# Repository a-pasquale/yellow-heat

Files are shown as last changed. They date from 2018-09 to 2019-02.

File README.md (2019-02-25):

# Yellow Heat vegetable oil burner monitoring system

More information about vegetable oil burner technology and installation for Yellow Heat burners is available at https://www.yellowheat.com/

## How it works
This monitoring system is designed to display current fuel level, record and display historical consumption of vegetable oil fuel, and display burner status. 

When the burner turns on or off, the device records the current fuel level. The monitoring device sends this data to the database. Cloud functions calculate fuel consumption when new data is posted in the database. The cross-platform app allows users to configure the monitoring device over bluetooth and displays current fuel level, total consumption, and historical usage. The cloud functions also provide notifications to the user and optionally to the fuel vendor when fuel level drops below a specificied point.

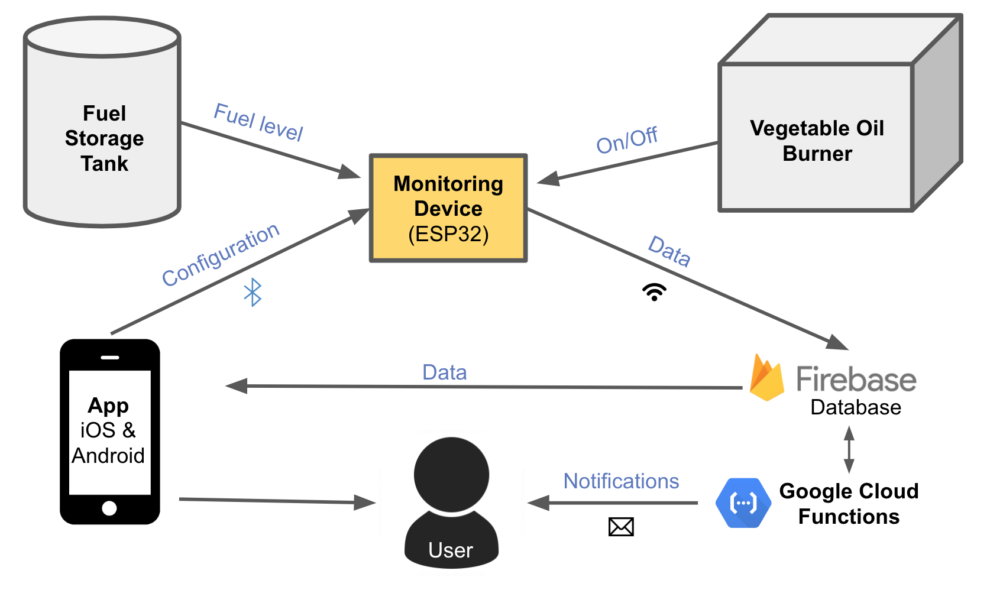
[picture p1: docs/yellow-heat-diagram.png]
Diagram


## Hardware

The Yellow Heat monitoring device is built on an [ESP32 microcontroller](http://esp32.net/). The ESP32 is a low-cost, low-power system on a chip (SoC) series with Wi-Fi & dual-mode Bluetooth capabilities. 

The device is powered with 110VAC converted to 12DC with a RECOM power supply (RAC02-12SGB). This is stepped down to 5V with  an LM2596 DC to DC Buck Converter to power the ESP32 board. The 12V also powers the fuel level sensor.

Fuel level is measured with a [Rochester 6860 magnetic liquid-level gauge](http://www.rochestergauges.com/products/8600.html). With an operating current of 7-8mA at VCC 12V, the guage returns an output of 0.5V - 4.5V. This is converted to a maximum of 3.3V using a voltage divider and indicates fuel level on pin 33.

Burner status (on/off) is measured using another LM2596 DC to DC Buck Converter which converts the 24V signal to 3.3V (HIGH) on pin 18.

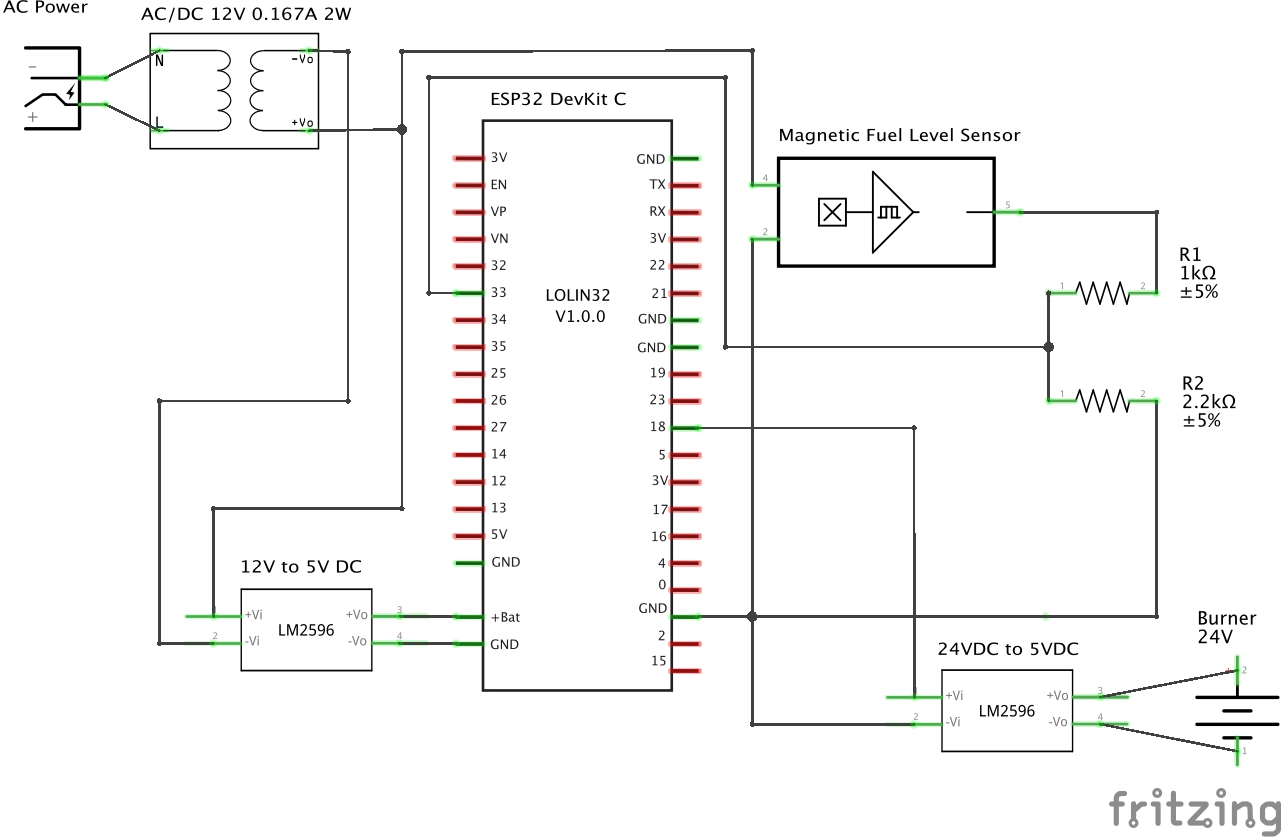
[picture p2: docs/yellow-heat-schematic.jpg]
Schematic


## Firmware
The firmware is developed with [Mongoose OS](https://github.com/cesanta/mongoose-os), an IoT Firmware Development Framework with Over-The-Air firmware updates and remote management, built in flash encryption, a device management dashboard service, and the ability to code in C or JavaScript.

Download this repository:
```bash
$ git clone https://github.com/a-pasquale/yellow-heat.git; cd yellow-heat
```
Build the firmware and flash the device:
```bash
$ mos build --platform esp32
$ mos flash
```
The Mongoose OS dashboard for debugging is very helpful:
```bash
$ mos ui
```

## Ionic App
A cross-platform Ionic App allows users to monitor burner stats, fuel level, and view history. The Ionic framework enables developers to build cross-platform apps in one codebase with the web technologies including Typescript, HTML, and SCSS.

More information about the app is available at [https://github.com/a-pasquale/yellow-heat-app](https://github.com/a-pasquale/yellow-heat-app).

## Google Cloud Functions
These functions calculate total fuel use for the burner and store the current burner status and fuel level. The functions also provide notifications to the user when fuel level drops too low and optionally to the vendor to deliver more fuel.

More information about the cloud functions is available at [https://github.com/a-pasquale/yellow-heat-firebase-functions](https://github.com/a-pasquale/yellow-heat-firebase-functions).

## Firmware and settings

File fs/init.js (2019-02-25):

load('api_config.js');
load('api_http.js');
load('api_gpio.js');
load('api_timer.js');
load('api_math.js');
load('api_adc.js');
load("api_rpc.js");
load('api_arduino_onewire.js');
load('ds18b20.js');
load('api_neopixel.js');

let ledPin = 19; // Not used
let btnPin = Cfg.get('app.button'); // Built-in button
let blePin = 4; // button to turn on BLE
let apiKey = Cfg.get('app.apiKey');
let url = 'https://yellow-heat.firebaseio.com/' + Cfg.get('user.uid') + '/' + Cfg.get('device.id');
let refresh_token = Cfg.get('user.refreshToken'); // Firebase refresh token
let token = '';          // Firebase id token
let refresh_time = 30; // minutes 
let temp_time = 5;     // minutes

let fuel = 33;      // pin for fuel guage
let full = 3935.0;  // value at full
let empty = 40.0;   // value at empty

let burn = 18;      // pin for burner
let burning = 0;    // burner status

// Initialize OneWire library
let ow = OneWire.create(21 /* pin */);
let n = 0;              // Number of sensors found on the OneWire bus
let rom = ['01234567']; // Sensors addresses
let tempF = 0;          // Current temperature

// Neopixel status LED
let neoPin = 2, numPixels = 1, colorOrder = NeoPixel.GRB;
let strip = NeoPixel.create(neoPin, numPixels, colorOrder);

// Colors for status indicator
function warningLED() {
  strip.setPixel(0 /* pixel */, 84, 0, 0); // Red
  strip.show();
}
function happyLED() {
  strip.setPixel(0 /* pixel */, 0, 84, 13); // Green
  strip.show();
}
function configLED() {
  strip.setPixel(0 /* pixel */, 84, 0, 84); // Purple
  strip.show();
}
warningLED(); // Start with warning light

let f = 0;              // Current fuel level
let t = 0;              // Current time

ADC.enable(fuel);
RPC.addHandler('readFuelLevel', function() {
  return ADC.read(33) / full;
});

RPC.addHandler('postToFirebase', function() {
  postFuelLevel();
}) 

// Remove these later
GPIO.set_mode(ledPin, GPIO.MODE_OUTPUT); // LED warning if unable to post data
GPIO.write(ledPin, 1);

// Input for from the heater: 24VDC = on, 0 = off
GPIO.set_mode(burn, GPIO.MODE_INPUT);
GPIO.set_int_handler(burn, GPIO.INT_EDGE_NEG, function(burn) {
  let calling = GPIO.read(burn);
  if (burning && !calling) {
    burning = 0;
    print('Turning off');
    postFuelLevel();
  } else if (!burning && calling) {
    burning = 1;
    print('Turning on');
    postFuelLevel();
  }
  print('Pin', burn, 'got interrupt');
}, null);
GPIO.enable_int(burn);

// Get a Firebase token
function getTokens() {
  HTTP.query({
    url: 'https://securetoken.googleapis.com/v1/token?key=' + apiKey,
    data: {
      'grant_type':	'refresh_token',
      'refresh_token': refresh_token
    },
    success: function(resp) {
      resp = JSON.parse(resp);
      token = resp.id_token;
      refresh_token = resp.refresh_token;
      print("tokens refreshed");
      print(resp.expires_in);
      print("expires in seconds");
      GPIO.write(ledPin, 1); // Turn on LED on successful post.
      happyLED();
    },
    error: function(err) {
      print("error refreshing tokens");
      print(JSON.stringify(err));
      warningLED();
      GPIO.blink(ledPin, 1000, 1000); // Blink warning LED.
    }
  });
}

// Refresh the tokens
Timer.set(refresh_time*60*1000 /* min x sec x ms */, Timer.REPEAT, function() {
  if (!bt_enabled) { getTokens() };
}, null);

function postFuelLevel() {
  f = ADC.read(fuel) / full;
  print("fuel:", f);
  t = Timer.now();
  print("Time:", t);
  
  HTTP.query({
    url: url + '/data.json?auth=' + token,
    data: {
      fuel: f,
      message: burning ? "on" : "off",
      timestamp: t
    },
    success: function(body, full_http_msg) {
      print("Posted successfully to Firebase: ", body);
      GPIO.write(ledPin, 1); // Turn on LED on successful post.
      happyLED();
      return body
    },
    error: function(err) { 
      print("An error occurred when posting to Firebase: ", err);
      GPIO.blink(ledPin, 1000, 1000); // Blink warning LED.
      warningLED();
      return error
    }
  });    
};

function readTemp() {
  if ((n = searchSens()) === 0) {
    print('No device found');
  }

  for (let i = 0; i < n; i++) {
    let t = getTempF(ow, rom[i]);
    if (isNaN(t)) {
      print('No device found');
      break;
    } else {
      print('Sensor#', i, 'Temperature:', t, '*F');
      tempF = t;
    }
  }
}
// Get temperature 
Timer.set(temp_time*60*1000 /* min x sec x ms */, Timer.REPEAT, function() {
  readTemp();
  HTTP.query({
    url: url + '/temp.json?auth=' + token,
    data: {
      temp: tempF,
      timestamp: Timer.now()
    },
    success: function(body, full_http_msg) { 
      print("Temp posted to Firebase");
      GPIO.write(ledPin, 1); // Turn off warning LED on successful post.
      happyLED();
    },
    error: function(err) { 
      print(err); 
      GPIO.blink(ledPin, 1000, 1000); // Blink warning LED.
      warningLED();
    },
  });
}, null);

RPC.addHandler('TempF', function() {
  readTemp();
  return tempF;
});

// Device online?
Timer.set(60*1000 /* every minute */, Timer.REPEAT, function() {
  let url2 = 'https://yellow-heat.firebaseio.com/users/' + Cfg.get('user.uid') + '/' + Cfg.get('device.id') + '/.json';
  HTTP.query({
    headers: { 
      'X-HTTP-Method-Override': 'PATCH'
    },
    url:  url2 + '?auth=' + token,
    data: {
      lastSeen: Timer.now()
    },
    success: function(resp) {
      print(resp); 
      print("Timestamp posted to Firebase");
      GPIO.write(ledPin, 1); // Turn off warning LED on successful post.
      happyLED();
    },
    error: function(err) { 
      print(err); 
      GPIO.blink(ledPin, 1000, 1000); // Blink warning LED.
      warningLED();
    },
  });
}, null);

// Builtin button posts to Firebase
GPIO.set_button_handler(btnPin, GPIO.PULL_UP, GPIO.INT_EDGE_NEG, 200, function() {
  // print("Button pushed. Posting to Firebase...");
  // postFuelLevel();
  Cfg.set({bt: {enable: true}});
  Cfg.set({wifi: {sta: {enable: false}}});
  Sys.reboot(0);
}, null);

// Enable BT for configuration by pressing the button.
GPIO.set_button_handler(blePin, GPIO.PULL_DOWN, GPIO.INT_EDGE_POS, 50, function() {
  Cfg.set({bt: {enable: true}});
  Cfg.set({wifi: {sta: {enable: false}}});
  Sys.reboot(0);
}, null);

// Enable BT so device can be configured. 
// Once Wifi is working, BT will be disabled automatically.
let bt_enabled = Cfg.get('bt.enable');
if (bt_enabled) {
  configLED();
  // Turn off BT and reboot in 2 min
  Timer.set( 2 * 60 * 1000, false, function() {
    Cfg.set({wifi: {sta: {enable: true}}});
    Sys.reboot(0);
  }, null);
} else {
  warningLED();
};
// Refresh tokens when connected to the network.
Event.addHandler(Event.CLOUD_CONNECTED, function() {
  getTokens();
}, null);
// Set status
Event.addHandler(Event.REBOOT, function() {
  strip.clear();
}, null);

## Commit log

2017-10-20 Write to firebase using the device id
2018-01-15 Read values from fuel level sender when triggered by burner call.
    [init.js]
2018-09-26 Add schematics
    [yellow_heat_schematic.fzz]
2018-10-17 Add DS18B20 temperature sensor.
2018-10-29 Use Firebase auth token. Blink LED when unable to post data.
2019-02-25 Update schematic
    [yellow_heat_schematic.fzz]
2019-02-25 Add LED indicator and last seen timestamp
